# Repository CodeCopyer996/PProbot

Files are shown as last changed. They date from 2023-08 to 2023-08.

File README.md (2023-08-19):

# PProbot
My personal robot project, including 3D-models, trajectory tracking algorithm and control code, etc.
2.ctrl_system: IDE:STM32CUBEIDE MCU:STM32F427IIH6
3.Model: Solidworks 3D models
4.Docs: Article & Logs
5.QT: some QT practices, useless
6.CAD: .dwg files
7.Matlab:SimMechanics visual simulation; Simulink Trajectory tracking control simulation; Robotics-toolbox kinematics simulation;
demo video: 【PProbot四关节转动演示】 https://www.bilibili.com/video/BV1uu4y117B4/?share_source=copy_web&vd_source=224ee29a92f0b972809e3df01ed2ee81
3Dmodel
matlab_robotic
realrobot

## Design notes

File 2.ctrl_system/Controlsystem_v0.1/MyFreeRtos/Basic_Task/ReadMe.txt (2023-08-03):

注意！！！此文件为基础文件，主要用于辅助完成其他任务，
具体包括：
1.LED函数定义
2.Key函数定义
3.Usart与printf函数重定义
4.DMA函数定义

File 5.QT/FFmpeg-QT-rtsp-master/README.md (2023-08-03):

#                                  2018年7月8日更---程序使用说明
（1）首先将代码下载到本地，并解压；
（2）下载附件中的FFmpeg压缩包，解压后文件夹以FFmpeg命名，并和源码放入同一文件夹下；
（3）利用Qt creator Debug/release后，将FFmpeg文件夹下“dll”文件夹中的所有文件复制到含有.exe文件的文件夹（名称为Debug或release）下；
（4）再次点击Debug或release即可正常运行。

# FFmpeg-QT实现摄像头rtsp实时显示
1. 程序运行平台：（1）win10 64bit         （2）Qt Creator 4.3.1
2. 程序需要的库：（1）Qt 5.9.1(MSVC 2015,32bit) （2）FFmpeg 2.5.2
3. 程序流程图：
	程序流程图如图1所示，图中所示的主函数部分主要完成界面的构建、播放线程的建立以及参考坐标系的建立。图1展示了整个程序的运行流程。

图1 程序流程图
 
4. 程序界面：
	程序运行界面如图2所示。

 图2 程序运行界面

5. 主要功能：
	该界面主要实现四个功能：
（1）.读取摄像头视频流（rtsp），并实时显示到主界面上（注：存在0.7s左右的延时，延时测试过程如图3所示）；

 图3 延时测试过程

（2）.将rtsp视频流经过FFmpeg解码后的YUV数据转化成RGB32数据，提取其中的R（红色）通道，并在界面中的小窗显示（如图2中的左上角部分）；
（3）.将水下机器人的横滚角反映在界面上（如图2中，中间部分的虚线“十字”为水平和竖直参考位置；实线“十字”为横滚运动后机器人相对参考位置的角度变化，图示为模拟横滚角为10度的情形）。
（4）.若程序掉电，再次上电后能够自动地建立连接。

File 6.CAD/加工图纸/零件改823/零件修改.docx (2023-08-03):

1. 大臂支架左：过盈孔大的太大了，箭头指的孔应该打27.9，结果打了28.5的孔，比轴承大了没法用，需重做；

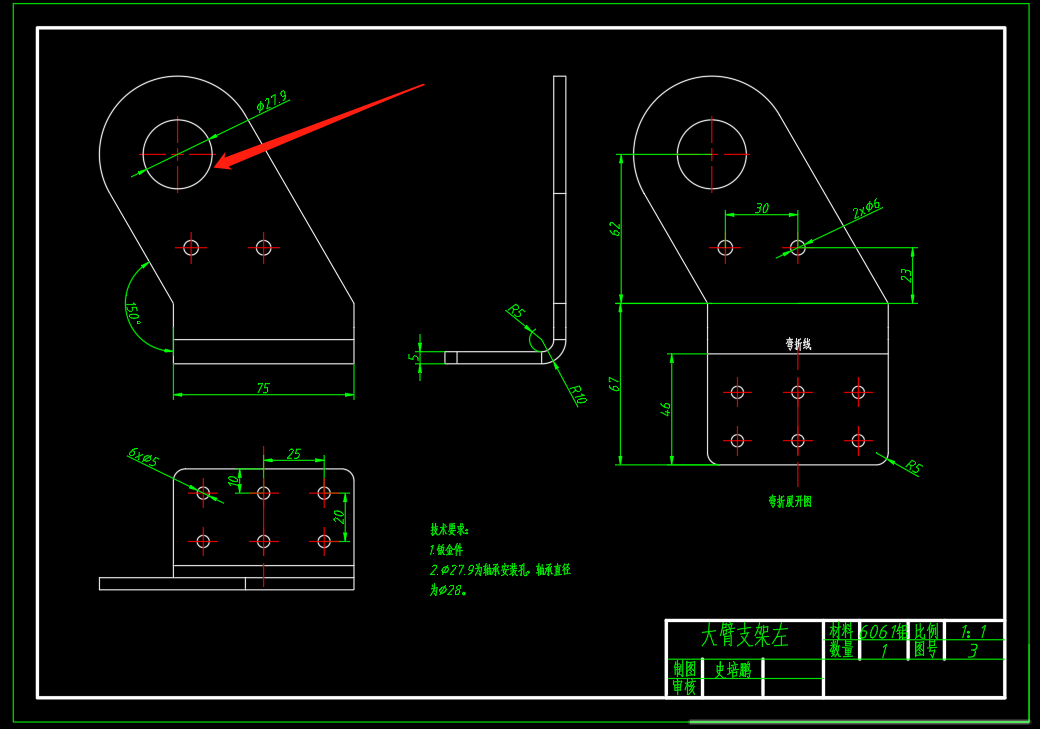
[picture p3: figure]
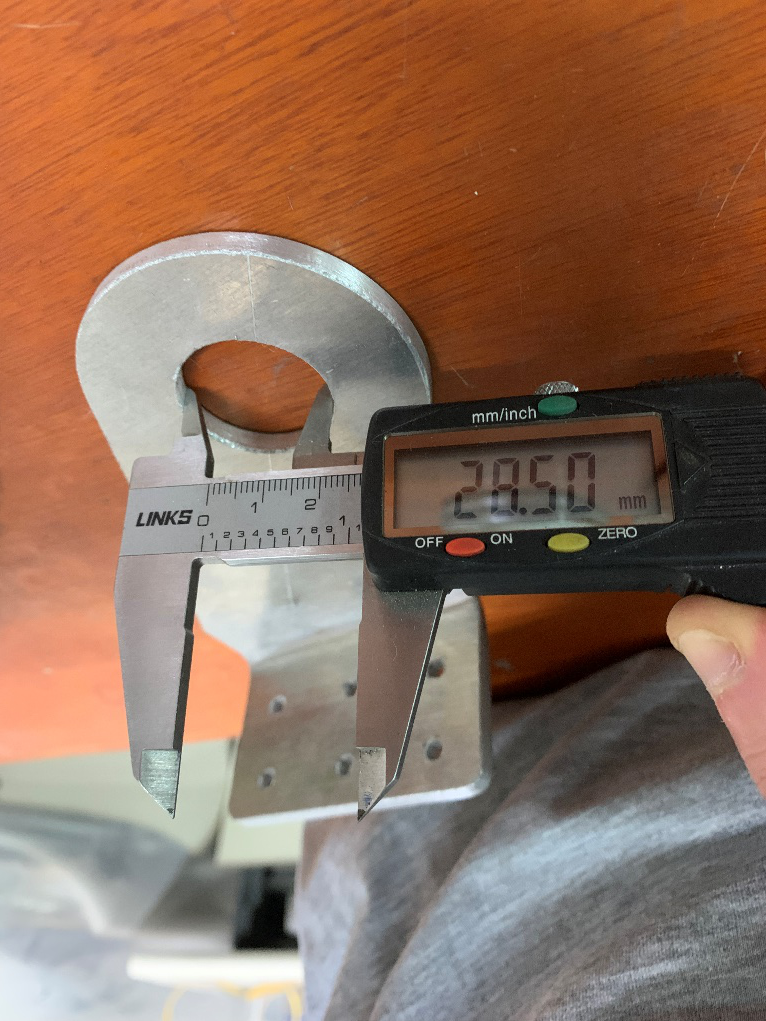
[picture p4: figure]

2. 小臂支架右，做的跟小臂支架左一样了，两个件孔是不一样的，需要重做；

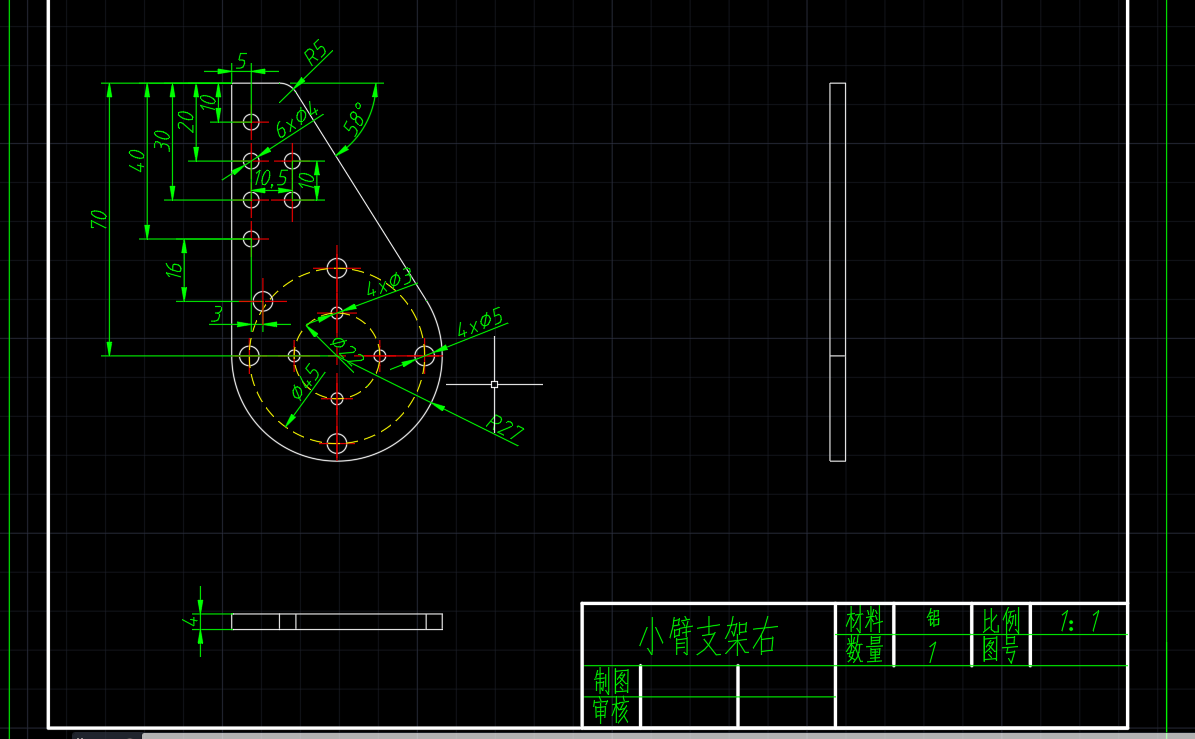
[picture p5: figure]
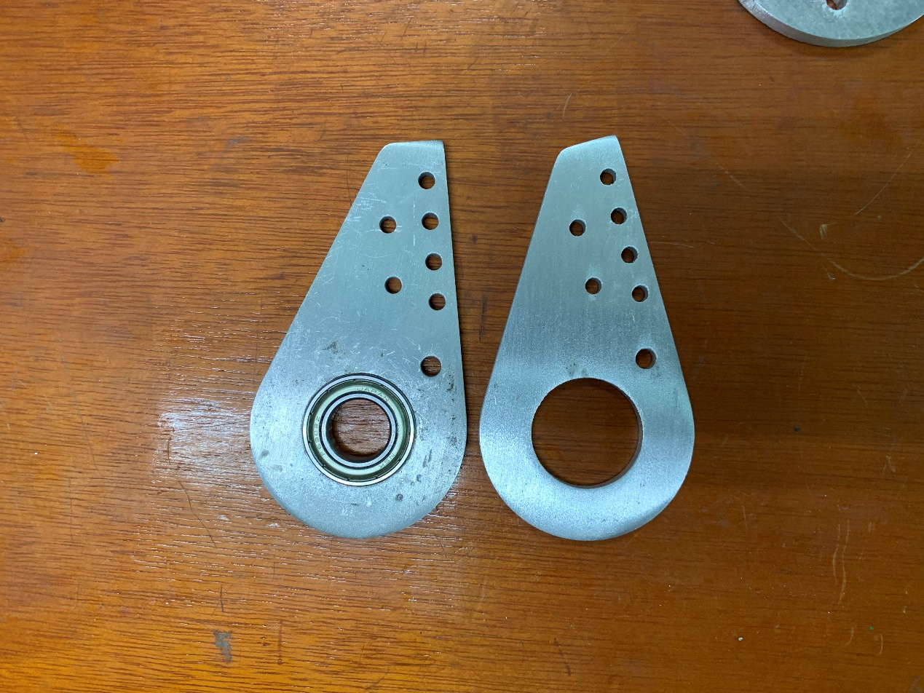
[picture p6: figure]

3. 大臂右，图纸少画了一组孔，可以修改；

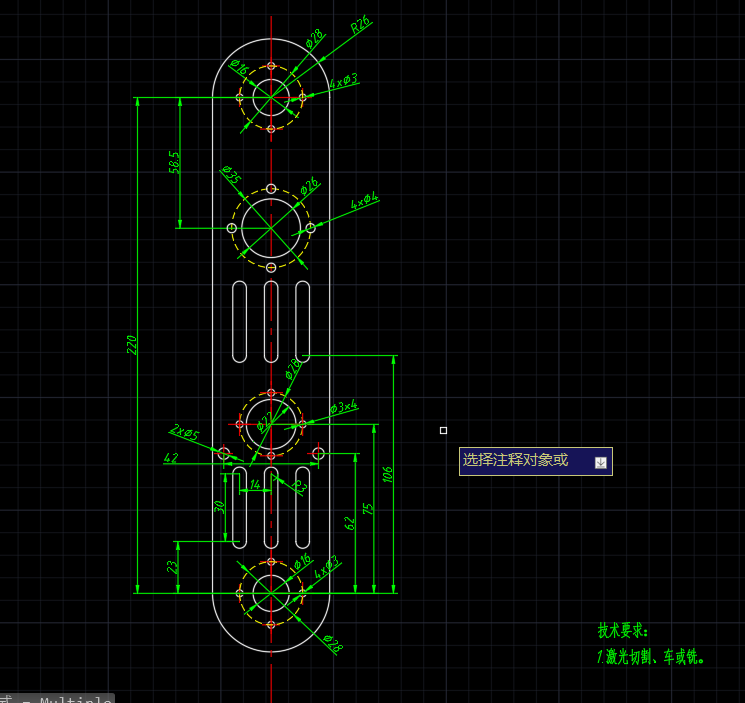
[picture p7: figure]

4. 大臂支架右：弯折方向反了，可以重新弯折；

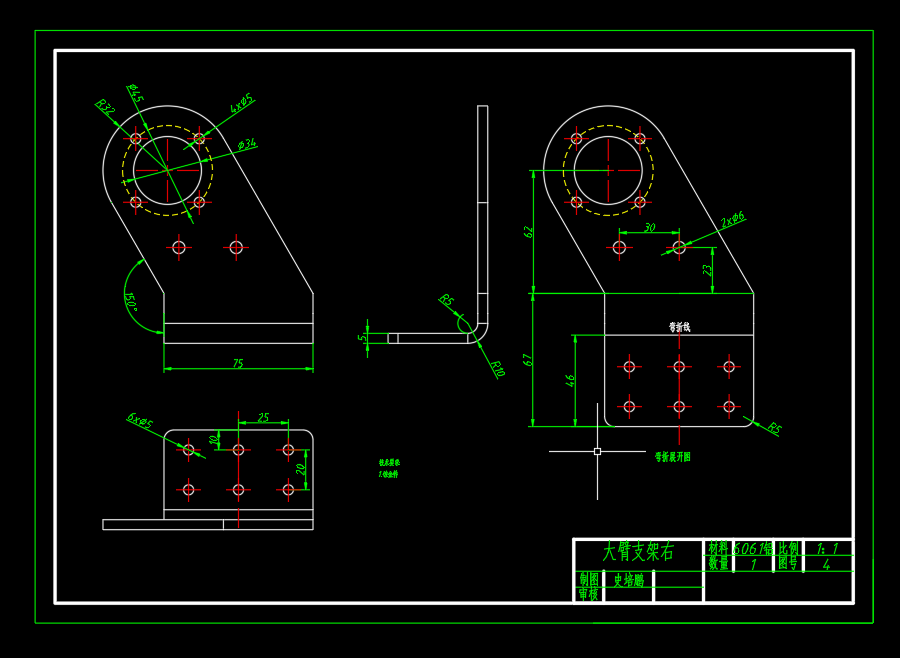
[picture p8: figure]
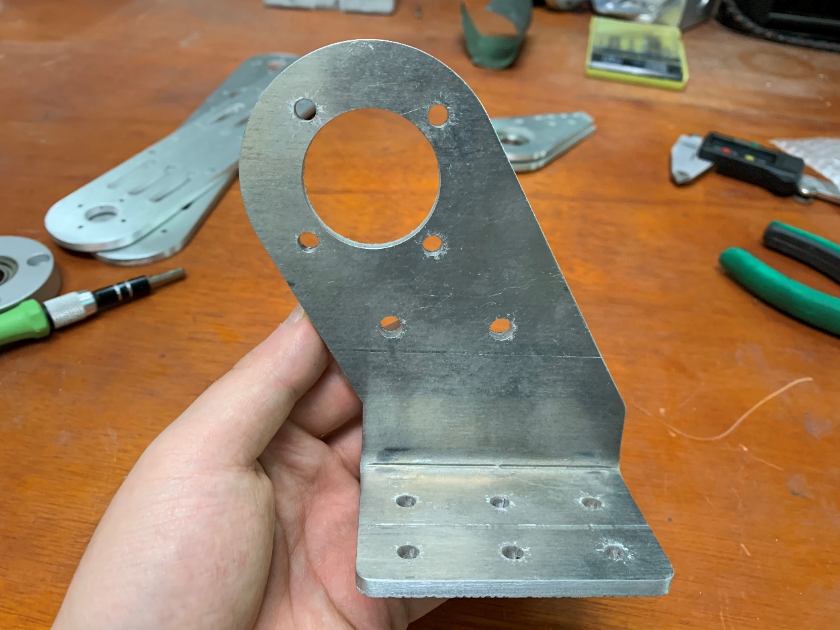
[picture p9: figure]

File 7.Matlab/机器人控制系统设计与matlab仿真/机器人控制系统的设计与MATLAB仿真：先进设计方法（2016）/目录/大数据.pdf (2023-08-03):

01 | Spark大数据分析与实战（大数据技术与应用丛书）
ISBN：9787302534327 | 作者：黑马程序员
定价：49.0元 | 出版日期：2019-09-01

传智播客编写，实用性强，案例翔实，配套数字资源丰富。

■PPT | □源码 | ■大纲 | □视频 | □教案 | □答案

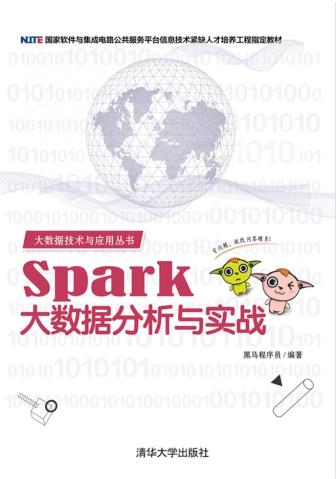
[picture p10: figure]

02 | 大数据安全与隐私保护（信息安全理论与技术系列丛书）
ISBN：9787302510451 | 作者：冯登国 等
定价：45.0元 | 出版日期：2018-02-01

“十三五”国家重点图书，全面阐述大数据安全与隐私保护领域理 论基础与最新进展。

■PPT | □源码 | □大纲 | □视频 | □教案 | □答案
03 | 大数据技术与应用（大数据技术与应用专业规划教材）
ISBN：9787302451815 | 作者：娄岩
定价：32.0元 | 出版日期：2016-01-01

本书是将大数据这一计算机前沿科学和基础教学有机结合的典范教 材，由浅入深地剖析了大数据的分析处理方法和技术手段。

■PPT | □源码 | □大纲 | □视频 | □教案 | □答案

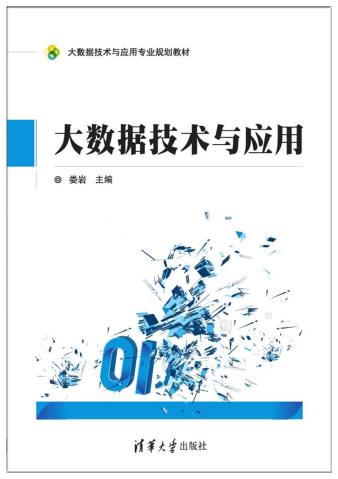
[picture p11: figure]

04 | 大数据可视化技术（大数据系列丛书）
ISBN：9787302449782 | 作者：周苏、张丽娜、王文
定价：44.5元 | 出版日期：2016-01-01

大数据可视化技术更注重技术的理解、掌握和应用，系统全面地介 绍可视化技术的基础知识和基本技能！

■PPT | □源码 | □大纲 | □视频 | □教案 | □答案

大数据挖掘及应用（大数据系列丛书） | 05
ISBN：9787302469278 | 作者：王国胤、刘群、于洪、曾宪华
定价：59.5元 | 出版日期：2017-07-01

本书是大数据系列丛书之一，涵盖大数据挖掘及应用领域的理论知 识、方法、技术、案例等重要内容，并配套视频课程及电子资源 ，是深入学习大数据挖掘理论和实践的专业教材。

■PPT | ■源码 | □大纲 | □视频 | □教案 | ■答案

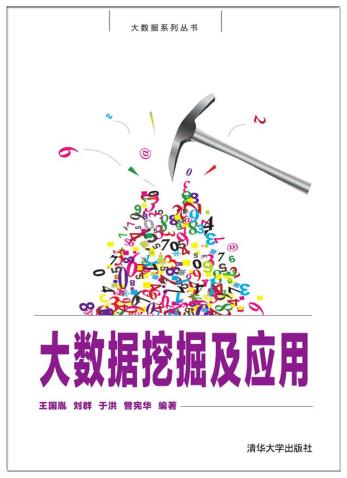
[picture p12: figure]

大数据挖掘与应用（大数据技术与应用专业规划教材） | 06
ISBN：9787302460435 | 作者：王振武
定价：49.5元 | 出版日期：2017-06-01

理论和实践相结合，充分融入产业界的先进理念，基于阿里云数加 平台进行演示，形象生动地使读者理解和掌握抽象的数据挖掘算法

■PPT | ■源码 | □大纲 | □视频 | □教案 | □答案
大数据智能分析 | 07

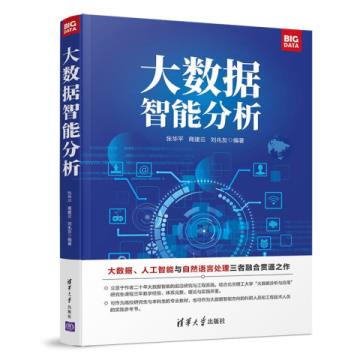
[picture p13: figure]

ISBN：9787302531173 | 作者：张华平、商建云、刘兆友
定价：59.8元 | 出版日期：2019-01-01

大数据智能，从数据量变到智能质变，提供课件及其他相关资源。

■PPT | □源码 | □大纲 | □视频 | □教案 | □答案
数据仓库与数据挖掘（第二版）（21世纪高等学校计算机专业核心课程规划... | 08
ISBN：9787302483991 | 作者：陈志泊、韩慧、王建新、孙俏、聂耿青
定价：39.0元 | 出版日期：2017-01-01

本书主要介绍数据仓库和数据挖掘技术的基本原理和应用方法

■PPT | □源码 | □大纲 | □视频 | □教案 | □答案

09 | 数据仓库与数据挖掘应用教程（21世纪高等学校电子商务专业规划教材）
ISBN：9787302430773 | 作者：李春葆、蒋林、陈良臣、喻丹丹、曾平
定价：39.5元 | 出版日期：2016-01-01

本书从介绍数据仓库和数据挖掘的基本概念出发，由简单到复杂 ，循序渐进介绍数据仓库和数据挖掘系统的开发过程，适合作为高 等学校大数据、电子商务专业教材

■PPT | □源码 | □大纲 | □视频 | □教案 | □答案

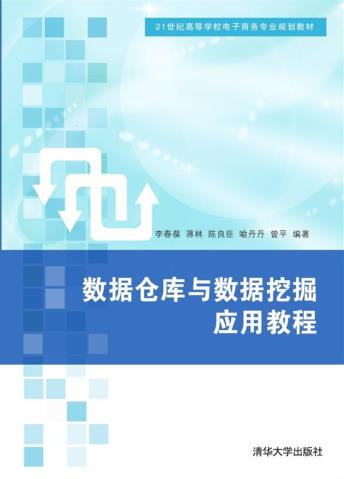
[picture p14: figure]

10 | 数据分析与数据挖掘（计算机科学与技术学科前沿丛书 计算机科学与技术...
ISBN：9787302493662 | 作者：喻梅 于健 主编；王建荣 王庆节 ...
定价：39.5元 | 出版日期：2018-04-01

“十三五”国家重点图书。紧密追踪当前科技前沿、数据科学热点 。算法由浅入深、由原理到应用，有利于学习和理解

■PPT | □源码 | □大纲 | □视频 | □教案 | □答案

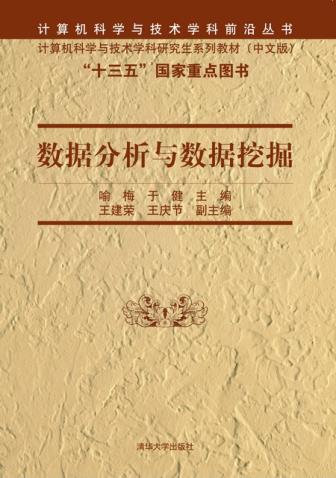
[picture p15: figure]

11 | 数据科学
ISBN：9787302436997 | 作者：朝乐门
定价：49.0元 | 出版日期：2016-08-01

本书是系统阐述数据科学的重要专著，深入浅出地讲解了大数据及 其背后的新理论、新方法与新技术，是大数据时代必读的经典书籍 之一。

■PPT | □源码 | □大纲 | □视频 | □教案 | □答案
12 | 数据科学理论与实践（第2版）（全国高校大数据教育联盟系列教材）

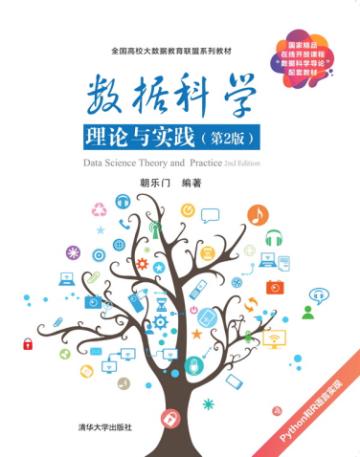
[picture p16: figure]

ISBN：9787302531913 | 作者：朝乐门
定价：69.8元 | 出版日期：2019-09-01

（1）国家精品开放在线课程《数据科学导论》的配套教材（2）一 本系统讲解全球范围内的数据科学的新理论与代表性实践的教材

■PPT | □源码 | □大纲 | □视频 | □教案 | □答案

数据科学理论与实践（全国高校大数据教育联盟系列教材） | 13
ISBN：9787302480549 | 作者：朝乐门
定价：59.0元 | 出版日期：2017-01-01

本书系统讲解数据科学的核心理论与典型实践，是一本“既有理论 高度，又有实践深度”的开创性教材。

■PPT | □源码 | □大纲 | □视频 | □教案 | □答案
数据可视化原理及应用（大数据技术与应用专业规划教材） | 14
ISBN：9787302531777 | 作者：樊银亭 夏敏捷 编著
定价：59.9元 | 出版日期：2019-01-01

本书理论与实际相结合，重点介绍最新的数据化技术D3，配套资源 丰富

■PPT | ■源码 | ■大纲 | □视频 | □教案 | □答案

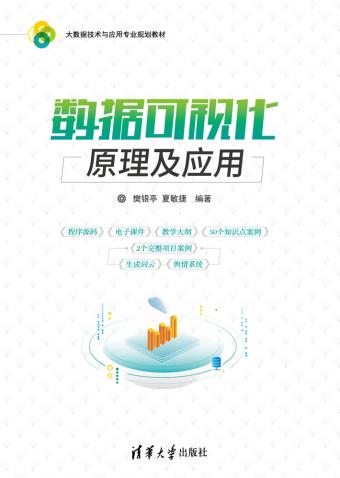
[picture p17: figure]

数据挖掘实用案例分析（大数据技术与应用专业规划教材） | 15
ISBN：9787302490494 | 作者：赵卫东 董亮
定价：49.0元 | 出版日期：2018-02-01

本书结合项目实践，对数据挖掘的核心问题进行了总结，并以案例 说明数据挖掘过程每个步骤需要关注之处；立足实际应用，突出实 际数据分析项目中的思路，以及数据分析中的难点。

■PPT | □源码 | □大纲 | □视频 | □教案 | □答案
数据挖掘算法原理与实现(第2版)（计算机系列教材） | 16

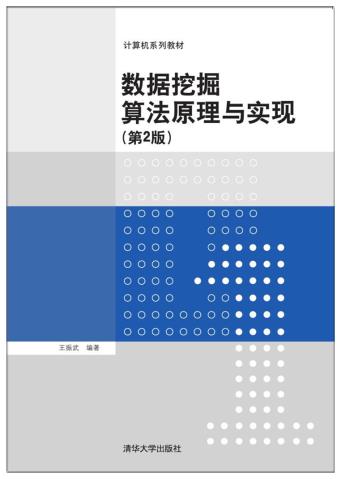
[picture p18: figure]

ISBN：9787302454151 | 作者：王振武
定价：35.0元 | 出版日期：2017-01-01

理论与实践结合非常实用的数据挖掘教材。

■PPT | □源码 | □大纲 | □视频 | □教案 | □答案

17 | 数据挖掘原理与算法（第3版）（21世纪高等学校计算机专业核心课程规划...
ISBN：9787302415817 | 作者：毛国君 段立娟
定价：49.0元 | 出版日期：2016-01-01

普通高等教育“十一五”国家级规划教材。

■PPT | □源码 | □大纲 | □视频 | □教案 | □答案
18 | 云计算导论（大数据技术与应用专业规划教材）
ISBN：9787302458050 | 作者：吕云翔、张璐、王佳玮
定价：29.0元 | 出版日期：2017-02-01

本书定位为“云计算导论”课程的专业教材，旨在传授读者云计算 的基础入门知识，本书也适合非计算机专业学生以及广大计算机爱 好者阅读

■PPT | □源码 | ■大纲 | □视频 | □教案 | □答案

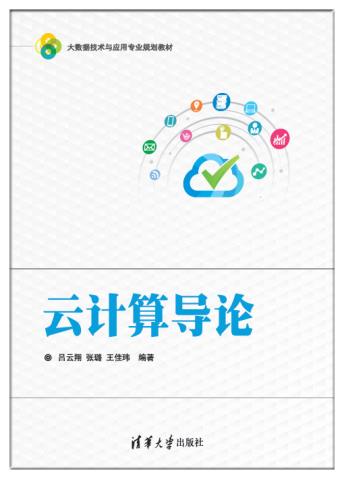
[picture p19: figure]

19 | 云计算与大数据技术理论及应用（大数据技术与应用专业规划教材）
ISBN：9787302524458 | 作者：林伟伟、彭绍亮
定价：89.0元 | 出版日期：2019-07-01

本书内容新颖先进，知识系统全面，技术深入易学

■PPT | □源码 | □大纲 | □视频 | □教案 | □答案

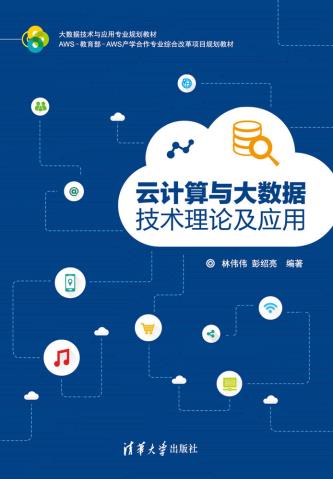
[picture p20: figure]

20 | Hadoop大数据技术原理与应用（大数据技术与应用丛书）
ISBN：9787302524403 | 作者：黑马程序员
定价：39.0元 | 出版日期：2019-05-01

传智博客倾情奉献，全面系统地讲解了Hadoop完整的技术体系，范 例翔实，配套教学资源丰富。

■PPT | □源码 | □大纲 | □视频 | □教案 | □答案

商务智能与数据挖掘（第2版）（大数据技术与应用专业规划教材） | 21
ISBN：9787302486312 | 作者：蔡晓妍、杨黎斌、张晓婷、李梅
定价：39.5元 | 出版日期：2018-03-01

阐述商务智能的两种关键技术——数据仓库和联机分析，最后介绍 数据挖掘在商务智能中的应用

■PPT | □源码 | □大纲 | □视频 | □教案 | □答案

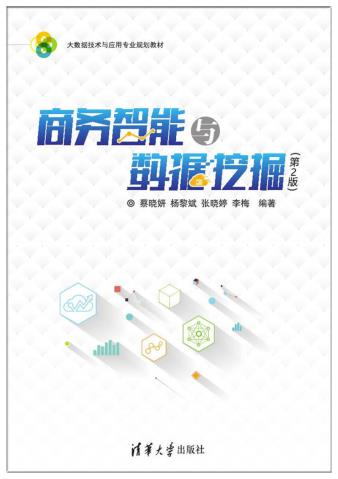
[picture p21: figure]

统计学——方法、数据与R的应用（大数据与人工智能技术丛书） | 22
ISBN：9787302529606 | 作者：刘超
定价：39.8元 | 出版日期：2019-09-01

以大量数据为基础，使用非常方便的R软件为读者呈现可见即可得 的统计分析过程。

■PPT | ■源码 | ■大纲 | □视频 | □教案 | □答案
虚拟化与云计算系统运维管理-微课版（21世纪高等学校计算机类课程创新... | 23
ISBN：9787302480532 | 作者：杨海艳、冯理明、张凌 主编，杜...
定价：49.5元 | 出版日期：2017-09-01

35段共500分钟微课视频，扫二维码直接观看，7大项目实战，详解 虚拟化与云计算基础系统运维管理。

■PPT | □源码 | ■大纲 | ■视频 | □教案 | □答案

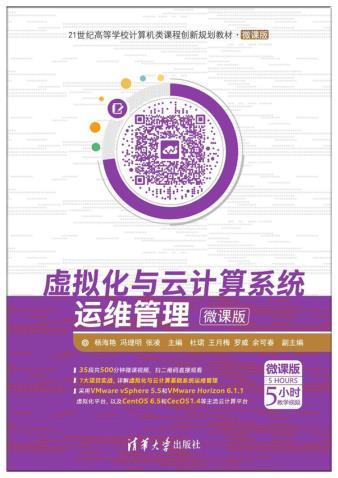
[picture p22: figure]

大数据技术与应用-微课视频版 | 24
ISBN：9787302538431 | 作者：肖政宏
定价：49.8元 | 出版日期：2020-06-01

本书可以作为高等院校大数据技术相关课程本科生教材，也可以作 为大数据技术基础相关课程研究生教材，还可以作为从事大数据相 关工作的工程技术人员的参考用书。

■PPT | ■源码 | ■大纲 | ■视频 | □教案 | ■答案

25 | 大数据可视化技术与应用-微课视频版
ISBN：9787302547501 | 作者：黄源
定价：49.8元 | 出版日期：2020-06-01

将理论与实践操作相结合，通过大量的案例帮助读者快速了解和应 用大数据分析的相关技术,并且对于书中重要的、核心的知识点加大 练习的比例，以使读者达到熟练应用的目的。

■PPT | ■源码 | ■大纲 | ■视频 | □教案 | □答案

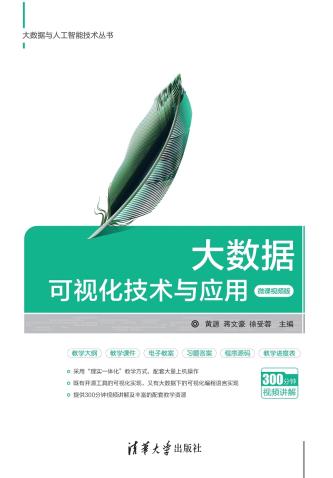
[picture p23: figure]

26 | 数据库技术及应用——基于SQL Server 2016和MongoDB
ISBN：9787302536185 | 作者：马忠贵
定价：69.8元 | 出版日期：2020-06-01

采用关系数据库（SQL Server 2016）和非关系数据库 （MongoDB）对照阐述，介绍各自的优势。

■PPT | ■源码 | ■大纲 | ■视频 | □教案 | □答案

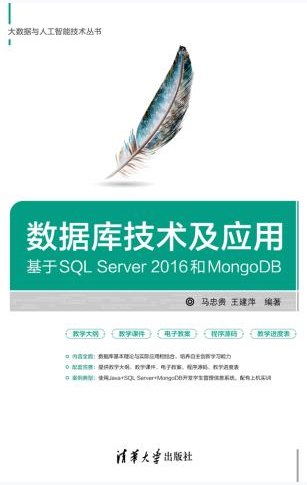
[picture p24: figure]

27 | Python数据分析与可视化-微课视频版
ISBN：9787302546665 | 作者：魏伟一
定价：49.0元 | 出版日期：2020-06-01
■PPT | ■源码 | ■大纲 | □视频 | □教案 | □答案
28 | Python爬虫大数据采集与挖掘-微课视频版

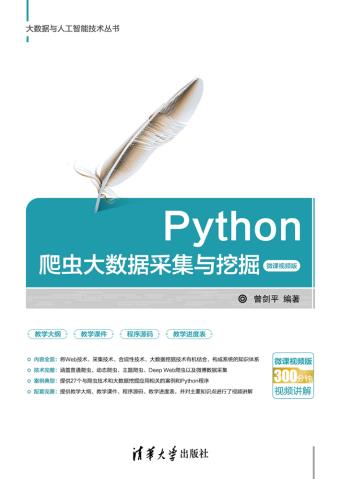
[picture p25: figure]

ISBN：9787302540540 | 作者：曾剑平
定价：59.8元 | 出版日期：2020-06-01

300分钟视频讲解

■PPT | ■源码 | ■大纲 | ■视频 | □教案 | ■答案

大数据分析：Python爬虫、数据清洗和数据可视化 | 29
ISBN：9787302530541 | 作者：黄源
定价：59.8元 | 出版日期：2020-06-01
大数据导论 | 30
ISBN：9787302541905 | 作者：张凯
定价：49.8元 | 出版日期：2020-06-01

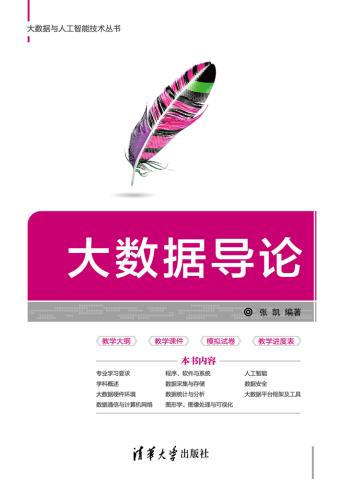
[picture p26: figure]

统计学——方法、数据与R的应用 | 31
ISBN：9787302529606 | 作者：刘超
定价：39.8元 | 出版日期：2019-09-01
大数据专业英语教程（大数据与人工智能技术丛书） | 32


ISBN：9787302526926 | 作者：张强华、刘俊辉、郑聪玲、司爱侠
定价：39.8元 | 出版日期：2019-07-01

以Unit为单位，每一Unit由以下几部分组成： 课文； 单词、词组 及缩略语； 难句讲解； 习题； 科技英语翻译知识； 阅读材料.

■PPT | □源码 | ■大纲 | □视频 | □教案 | □答案

33 | 云计算与大数据技术（大数据与人工智能技术丛书）
ISBN：9787302501466 | 作者：吕云翔、钟巧灵、张璐、王佳玮
定价：35.0元 | 出版日期：2018-01-01

注重云计算与大数据基本概念的讲解，以案例的方式梳理知识脉络 和要点，提供综合云计算实验案例

■PPT | □源码 | ■大纲 | □视频 | □教案 | □答案
34 | Python数据分析与实践
ISBN：9787302515791 | 作者：柳毅
定价：59.0元 | 出版日期：2019-06-01

浙江省“十三五”教材

■PPT | ■源码 | ■大纲 | ■视频 | □教案 | ■答案


35 | Python机器学习——数据分析与评分卡建模（微课版）
ISBN：9787302516842 | 作者：翟锟
定价：49.0元 | 出版日期：2019-05-01

本书从零基础入门，注重实战，内含10个学习实例，3个完整的项 目案例，详细讲解了Python的环境搭建、基本语法结构、趣味应用 、分析与建模以及完整的项目案例。

■PPT | ■源码 | □大纲 | ■视频 | □教案 | □答案


36 | Hadoop+Spark大数据技术（微课版）
ISBN：9787302514275 | 作者：刘彬斌
定价：69.0元 | 出版日期：2018-01-01

内容分为大数据系统基础、Hadoop技术、Spark技术和项目实战4部 分。其中，Linux是学习大数据技术的基础，先从Linux入手，打下 坚实的基础，之后才能更好地学习Hadoop和Spark。

■PPT | ■源码 | □大纲 | ■视频 | □教案 | □答案

Python网络编程(Linux) | 37
ISBN：9787302504832 | 作者：赵宏
定价：39.0元 | 出版日期：2018-01-01

本书选用各项性能指标优良的Ubuntu作为Linux系统实例，以 Python为编程语言，理论结合实践，系统地讲解网络各层次的功能 、所包含的常用协议、数据报文格式，并给出实际操作的程序实例 。

■PPT | ■源码 | □大纲 | □视频 | □教案 | ■答案


机器学习入门到实战——MATLAB 实践应用 | 38
ISBN：9787302495147 | 作者：冷雨泉
定价：59.0元 | 出版日期：2019-03-01
在线广告——互联网广告系统的架构及算法 | 39
ISBN：9787302526520 | 作者：张亚东
定价：69.8元 | 出版日期：2019-08-01

微博技术总监详解互联网广告系统的架构及算法，揭秘互联网商业 变现技术，众多互联网公司管理层与技术人员推荐阅读。

■PPT | □源码 | □大纲 | □视频 | □教案 | □答案


大话数据科学——大数据与机器学习实战（基于R语言） | 40
ISBN：9787302551300 | 作者：陈文贤
定价：128.0元 | 出版日期：2020-07-01

多图多思想，缜密学习思维导图，全套学习课件，全彩印刷、卓越 体验。学习数据科学，看陈文贤老师的就对了。

■PPT | □源码 | □大纲 | □视频 | □教案 | □答案

41 | 大数据技术（微课版）（面向新工科专业建设计算机系列教材）
ISBN：9787302553632 | 作者：曹洁、孙玉胜
定价：59.0元 | 出版日期：2020-08-01

学习大数据技术非常实用的教材。

■PPT | □源码 | □大纲 | □视频 | □教案 | □答案


42 | 云计算导论（第2版）（大数据与人工智能技术丛书）
ISBN：9787302536901 | 作者：吕云翔
定价：49.8元 | 出版日期：2020-06-01

本书从云计算最基本的概念开始，由浅入深地带领读者领会云计算 的精髓，以梳理知识脉络和要点的方式，带领读者登堂入室。

■PPT | ■源码 | ■大纲 | ■视频 | □教案 | ■答案
43 | 大数据技术基础（21世纪高等学校通识教育规划教材）


ISBN：9787302557531 | 作者：宋旭东
定价：59.0元 | 出版日期：2020-08-01

融会贯通大数据概念与大数据技术及应用，便于读者更好理解和掌 握大数据技术及应用。

■PPT | ■源码 | ■大纲 | □视频 | □教案 | □答案

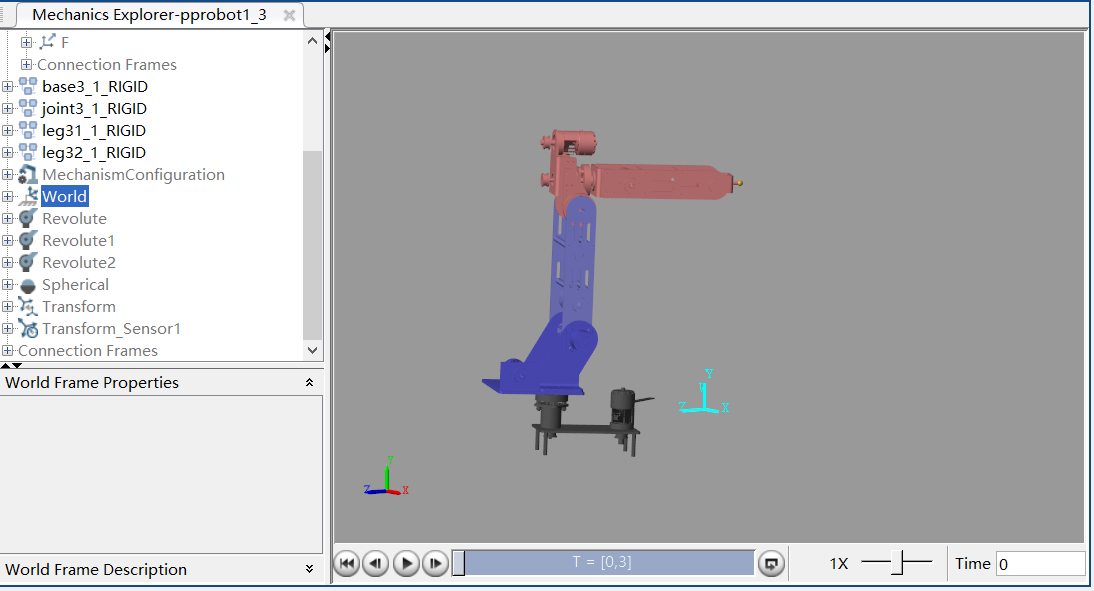
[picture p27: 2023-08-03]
7.Matlab/simulink_cut.png

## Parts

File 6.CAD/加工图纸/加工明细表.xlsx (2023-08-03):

名称 | 材料 | 板厚 | 数量 | 单价 | 总价 | 备注
大臂支架右 | 铝 | 5 | 1
大臂支架左 | 铝 | 5 | 1
小臂中 | 铝 | 4 | 1
小臂中支架 | 铝 | 4 | 1
爪 | 铝 | 4 | 1
大臂右 | 铝 | 5 | 1
大臂左 | 铝 | 5 | 1
小臂左 | 铝 | 5 | 1
小臂右 | 铝 | 5 | 1
小臂支架左 | 铝 | 4 | 1
小臂支架右 | 铝 | 4 | 1
轴承安装板 | 铝 | 4 | 1
底板F1 | 钢 | 5 | 1
底板F2 | 钢 | 5 | 1
61902法兰轴 | 铝 |  | 6
旋转轴 | 铝 |  | 3
 |  |  | 23 |  | 0

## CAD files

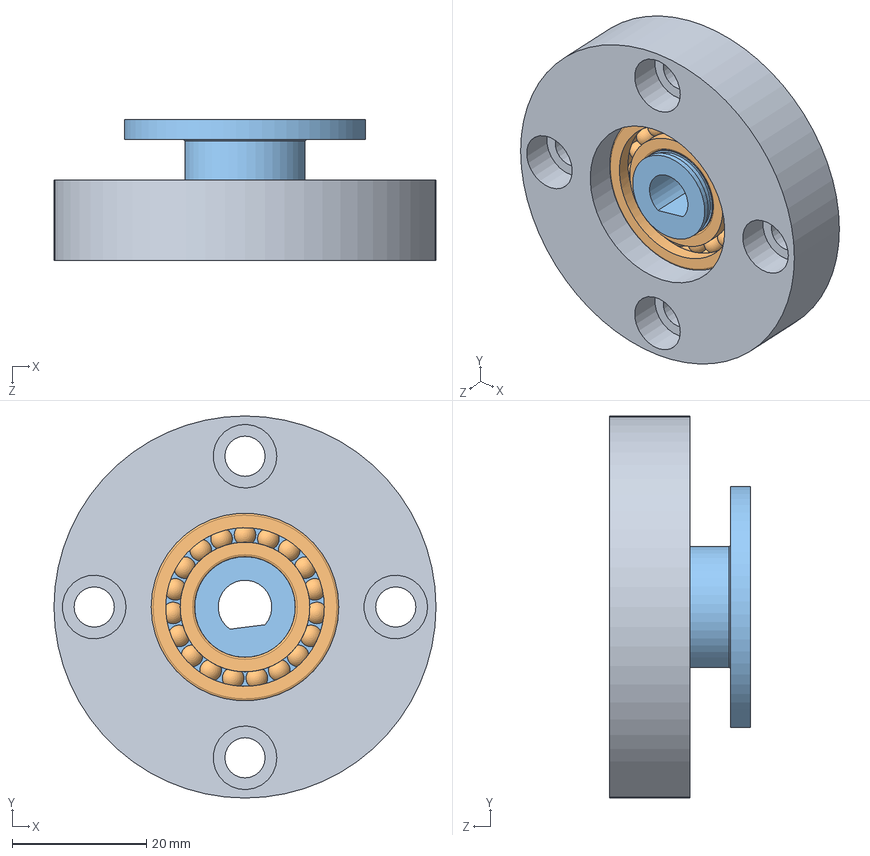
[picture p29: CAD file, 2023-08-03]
3.Model/轴承座.SLDASM
57.0 x 57.0 x 21.0 mm
轴承座
deep groove ball bearings gb
61902法兰

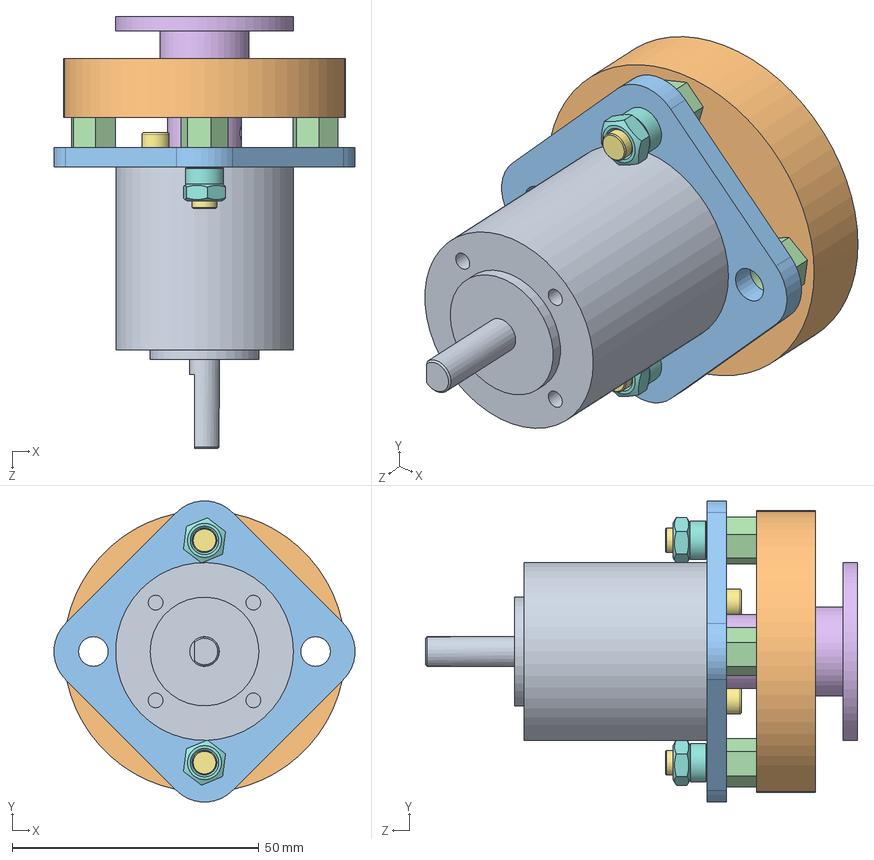
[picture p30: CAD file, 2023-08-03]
3.Model/减速器关节.SLDASM
60.9 x 60.9 x 87.5 mm
27：1双轴减速器
轴承座
减速器固定
铜柱M6x6 x 4
deep groove ball bearings gb
61902法兰
hexagon socket head cap screws gb x 4
prevailing torque type style 1 gb x 2

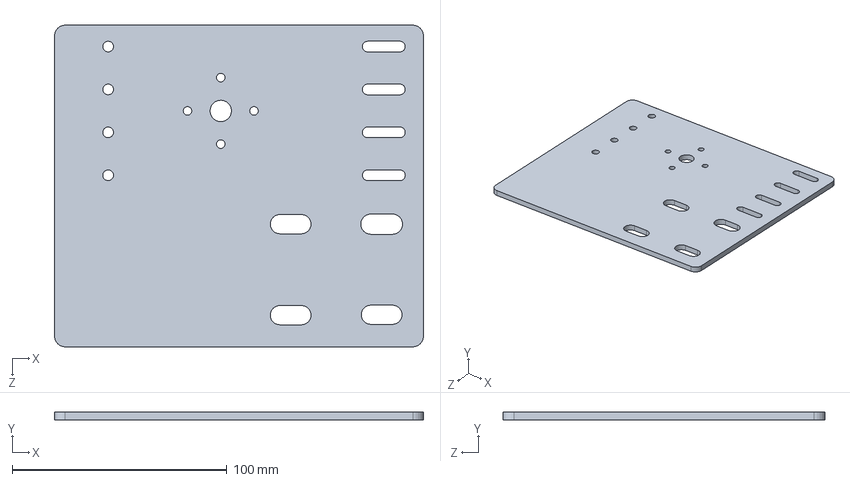
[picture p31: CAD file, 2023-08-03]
3.Model/对称支架.SLDPRT
172.0 x 3.68 x 150.0 mm

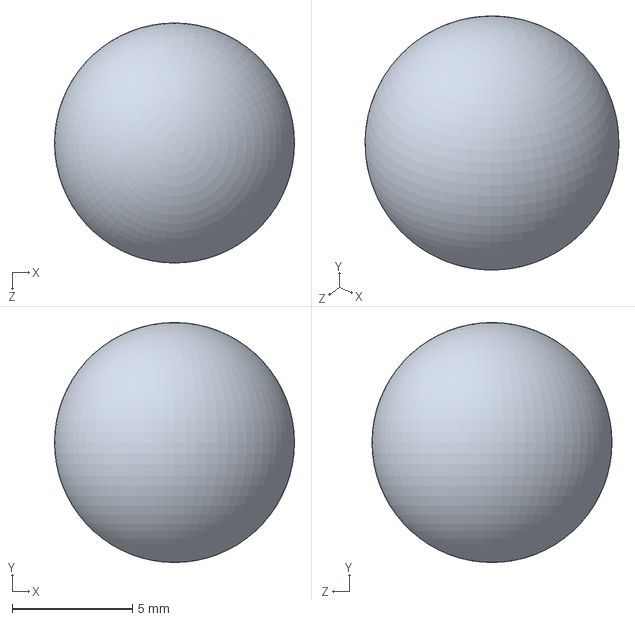
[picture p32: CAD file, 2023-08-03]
7.Matlab/ppRobot_matlab1.4/ball3.SLDPRT
10.0 x 10.0 x 10.0 mm

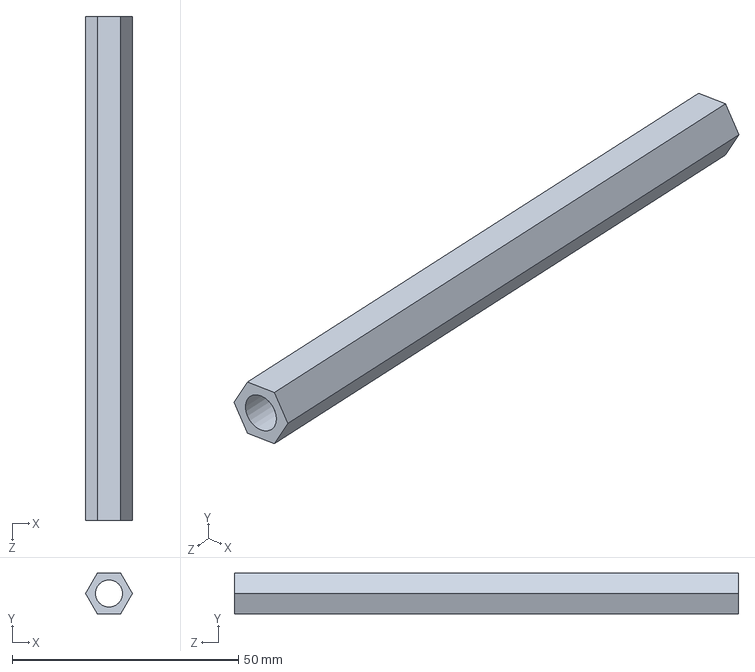
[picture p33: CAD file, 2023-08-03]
3.Model/111.5铜柱.SLDPRT
10.4 x 9.00 x 111.5 mm

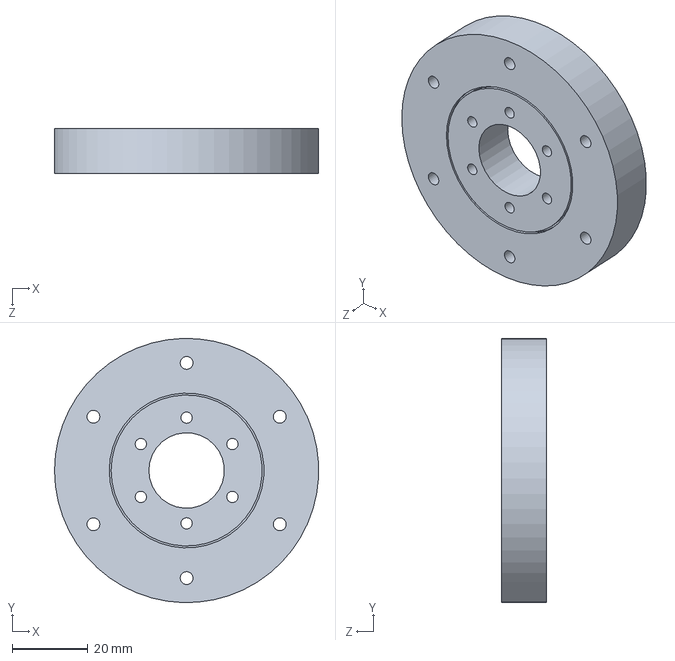
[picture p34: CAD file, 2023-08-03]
3.Model/交叉滚子轴承.SLDPRT
69.9 x 70.0 x 12.0 mm

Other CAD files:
6.CAD/加工图纸/底板F1.dwg
6.CAD/加工图纸/钢板类/底座F1_NO.1.dwg
6.CAD/加工图纸/铝板类/平板类（激光切割）/小臂左.dwg
6.CAD/加工图纸/铝板类/钣金板类/爪.dwg
6.CAD/加工图纸/零件改823/大臂支架左.dwg
6.CAD/加工图纸/云台法兰盘64.dwg
6.CAD/加工图纸/轴类/旋转轴.dwg
6.CAD/加工图纸/钢板类/底板F2_NO.2.dwg
6.CAD/加工图纸/铝板类/平板类（激光切割）/大臂左.dwg
6.CAD/加工图纸/铝板类/钣金板类/小臂中支架.dwg
6.CAD/加工图纸/零件改823/小臂支架右.dwg
7.Matlab/ppRobot_matlab1.4/ball3_默认_sldprt.STEP
3.Model/27：1双轴减速器.SLDPRT
3.Model/58铜柱.SLDPRT
3.Model/61902关节.SLDASM
3.Model/61902关节光孔.SLDASM
3.Model/61902法兰.SLDPRT
3.Model/61902法兰光孔.SLDPRT
3.Model/61902轴承座.SLDPRT
3.Model/61902轴承座薄.SLDPRT
3.Model/6902带挡边轴承.SLDPRT
3.Model/71铜柱.SLDPRT
3.Model/lianzhouqi.SLDPRT
3.Model/云台旋转板.SLDPRT
3.Model/云台法兰.SLDPRT
3.Model/云台法兰2.SLDPRT
3.Model/云台法兰42.SLDPRT
3.Model/云台联轴器8-10.SLDPRT
3.Model/减速器固定.SLDPRT
3.Model/同步轮6.SLDPRT
3.Model/同步轮8.SLDPRT
3.Model/地板.SLDPRT
3.Model/大臂.SLDPRT
3.Model/大臂左.SLDPRT
3.Model/大臂支架.SLDPRT
3.Model/大臂支架右.SLDPRT
3.Model/大臂支架左.SLDPRT
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

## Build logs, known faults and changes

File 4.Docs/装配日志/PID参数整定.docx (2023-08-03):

位置PID

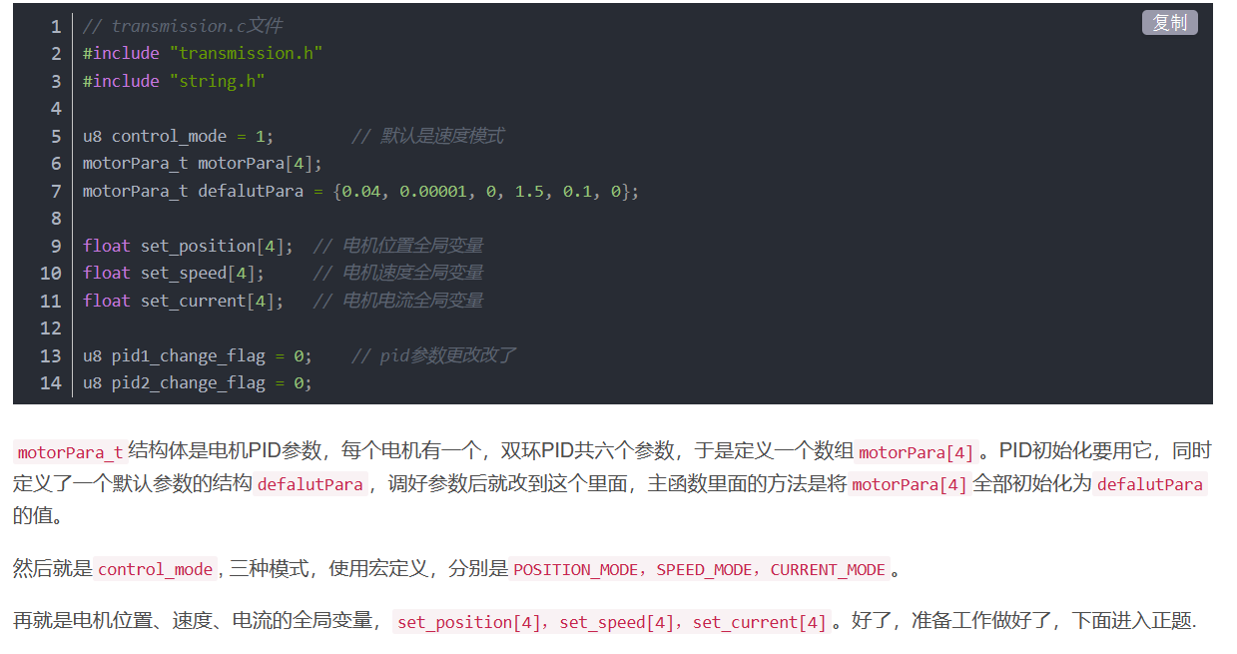
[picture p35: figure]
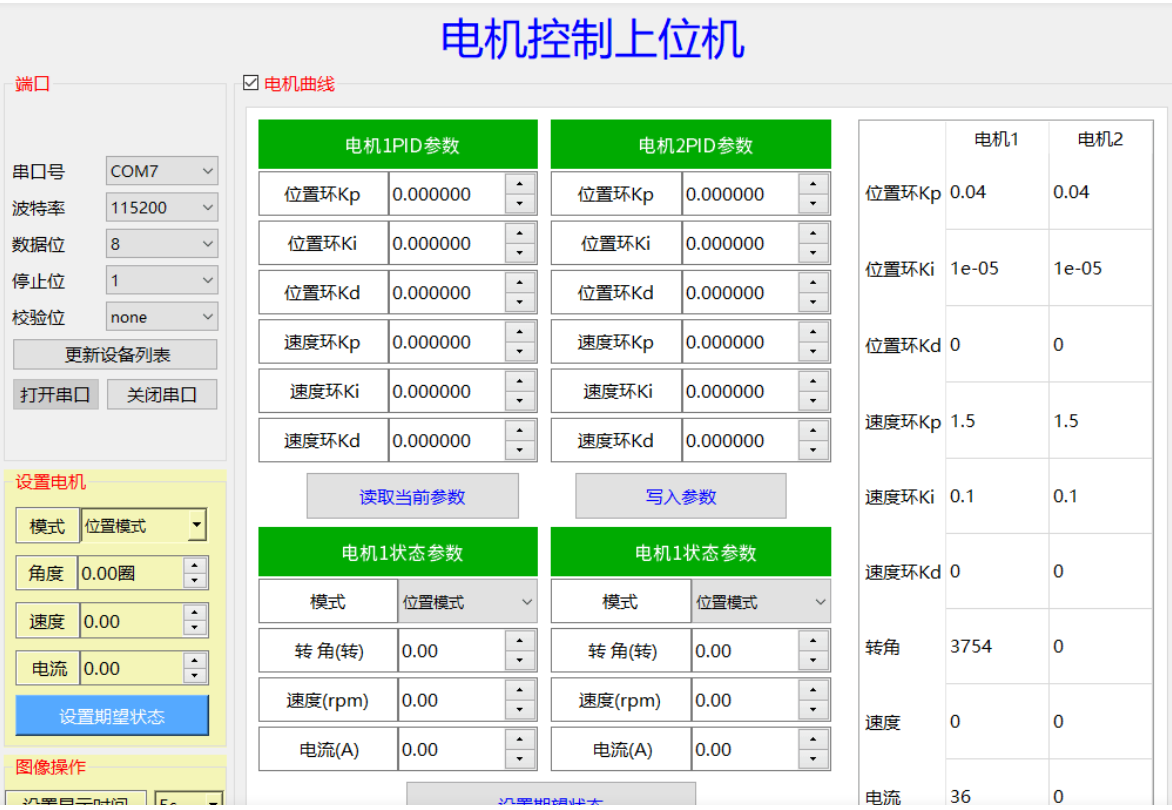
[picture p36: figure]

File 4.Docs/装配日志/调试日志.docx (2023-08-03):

6/16/2023 10:56 AM

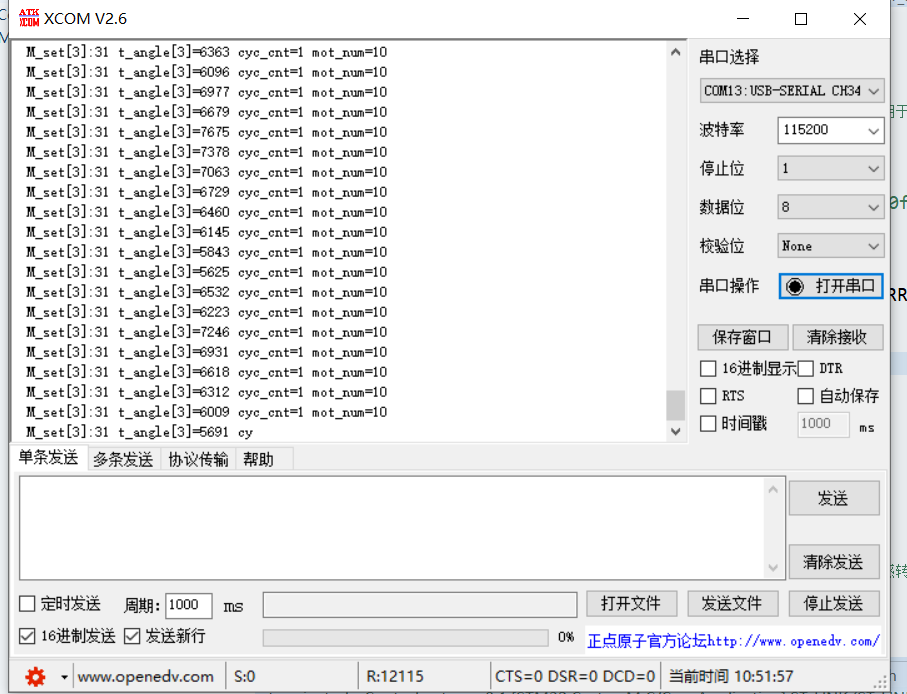
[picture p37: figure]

Issue:

转子转角更新出现问题，不符合设定的更新逻辑；（这个问题不应该出现

另外需要找到更好转子转数的判断条件，转子转速过快，大于feedback的时间间隔，就是在两个feedback时间间隔内，转子可能已经转了一圈或者更多，故在当前判断条件下会出现转了一圈甚至两圈但转数并不更新的情况，甚至在一段时间内转速恰好卡在这个bug区间，导致转子转数一直无法更新；

6/16/2023 11:34 AM

最终稳定：在一段较长时间内不再有波动，并且可以继续发送新的指令；

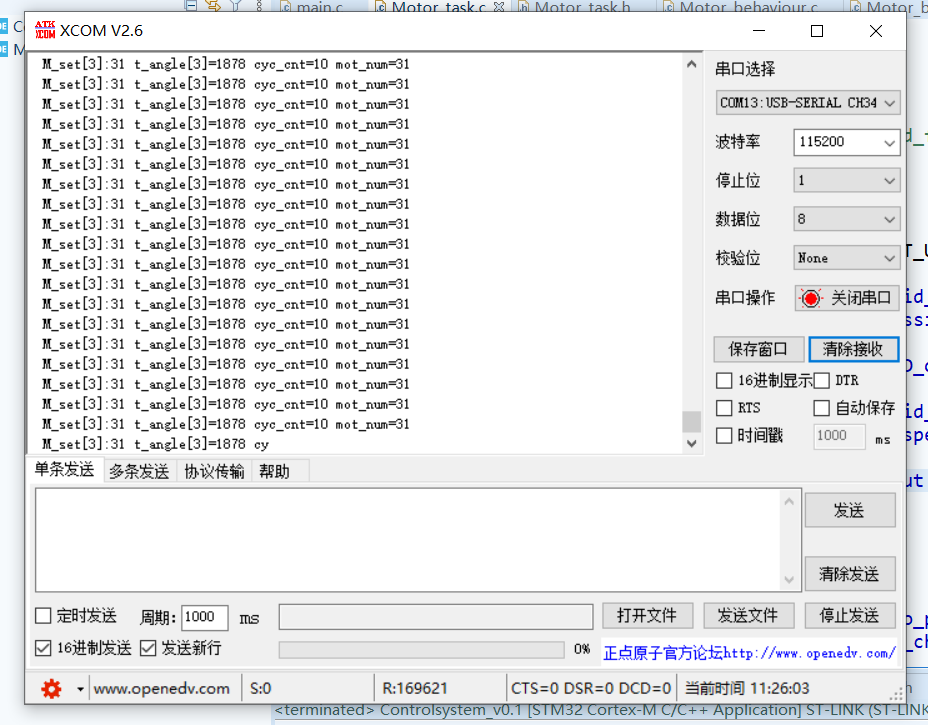
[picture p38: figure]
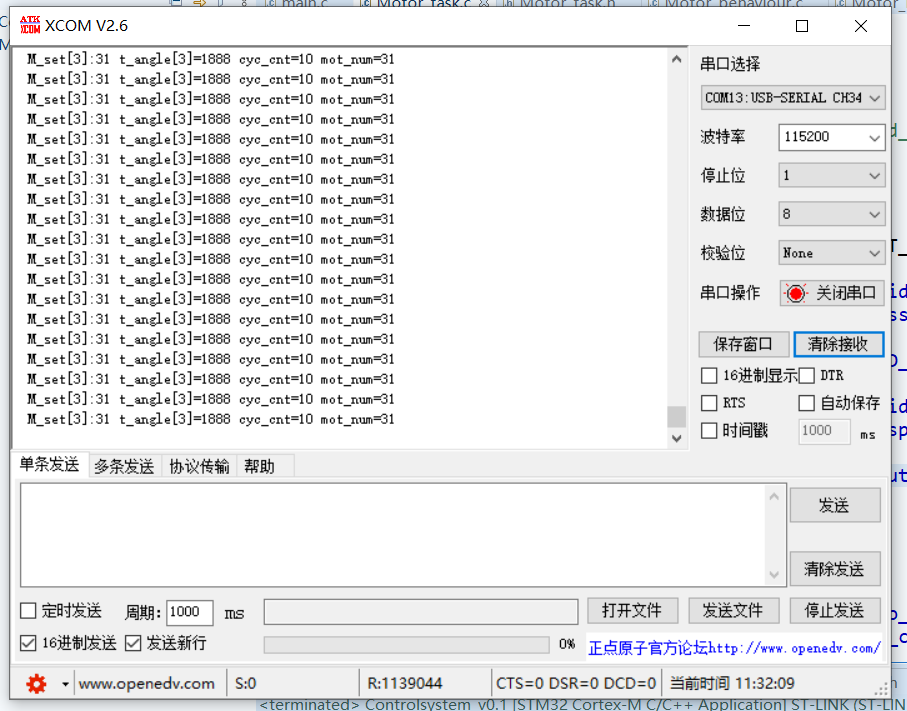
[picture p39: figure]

6/25/2023 4:28 PM

调试日志

Issue: cyc_cnt转数更新很魔性，不按规则来，查看后发现last_angle更新竟然比angle大

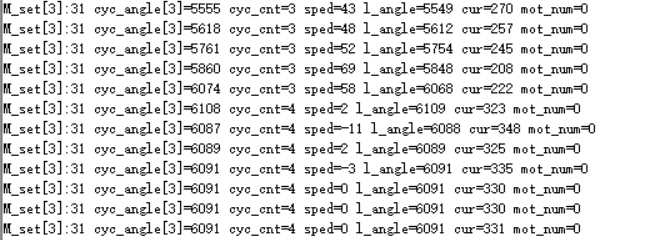
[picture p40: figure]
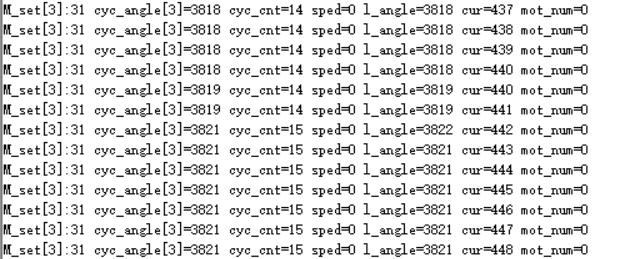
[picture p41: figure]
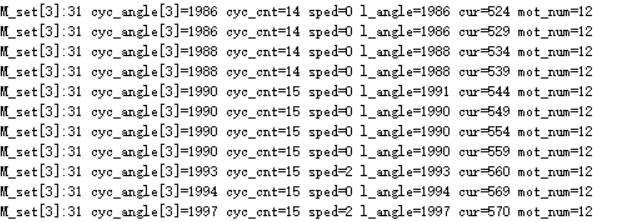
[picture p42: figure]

每次last_angle都比angle大1，就很离谱？？？而真正需要更新转数的情况一个都不更新，如下：

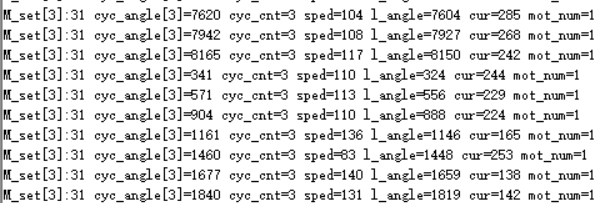
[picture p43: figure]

并且由此发现电机测量数据是自动更新的，不随feedback函数的频率更新，且更新速度更快，导致last_angle已经跟angle数值很接近了，无法再按照两数值的差值作为判断条件；

6/26/2023 8:33 PM

为解决电机内部编码器last_angle更新过快的问题，自行定义一个llast_angle，只在每次feedback函数时更新，这样当前angle和last_angle更新速率就保持一致了，解决了此问题，cyc_numcnt更新比较平稳，在此情况下电机输出轴的位置PID可以达到比较好的效果。

New issues:

1. 电机轴位置PID追踪目标值太慢了，解决：需要调参；
2. 当达到目标值附近时，电机速度变慢暂停，停止瞬间会出现speed反向的问题（应该是惯性导致），由于speed方向作为判定条件，会导致cyc_numcnt出现问题，比如正向转了一圈却因为暂停时出现负的速度导致圈数-1。解决：判定条件不再简单的speed<0或>0，令其>10 or <-10 ,简单滤波防抖；同理，cyc_numcnt转数更新的判定条件也采用的这种思路。

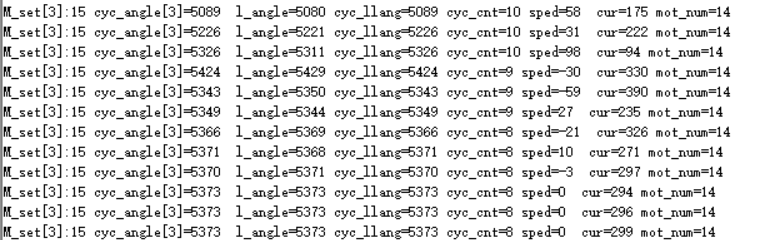
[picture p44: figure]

还是会出现这种极端情况，但是少了很多，调节了PID参数后旋转比较稳定。

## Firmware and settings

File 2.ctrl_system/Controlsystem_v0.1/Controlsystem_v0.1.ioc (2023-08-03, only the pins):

Mcu.UserName=STM32F427IIHx
PA13.Signal=SYS_JTMS-SWDIO
PA14.Signal=SYS_JTCK-SWCLK
PB0.Signal=ADCx_IN8
PB1.GPIO_Label=PRE_CLK1
PB1.Signal=GPIO_Output
PB2/BOOT1.GPIO_Label=USER_KEY
PB2/BOOT1.Signal=GPIO_Input
PB3.Signal=SYS_JTDO-SWO
PB6.Signal=USART1_TX
PB7.Signal=USART1_RX
PC14/OSC32_IN.Signal=RCC_OSC32_IN
PC15/OSC32_OUT.Signal=RCC_OSC32_OUT
PC3.GPIO_Label=PRE_DAT1
PC3.Signal=GPIO_Input
PD0.Signal=CAN1_RX
PD1.Signal=CAN1_TX
PD5.Signal=USART2_TX
PD6.Signal=USART2_RX
PD8.Signal=USART3_TX
PD9.Signal=USART3_RX
PE0.Signal=UART8_RX
PE1.Signal=UART8_TX
PE11.GPIO_Label=LED1
PE11.Signal=GPIO_Output
PE12.Signal=SPI4_SCK
PE4.GPIO_Label=NRF24L01_SPI_NSS
PE4.Signal=GPIO_Output
PE5.Signal=SPI4_MISO
PE6.Signal=SPI4_MOSI
PE7.Signal=UART7_RX
PE8.Signal=UART7_TX
PF10.GPIO_Label=NRF24L01_IRQ
PF10.Signal=GPIO_Input
PF14.GPIO_Label=LED0
PF14.Signal=GPIO_Output
PF6.GPIO_Label=SPI5_NSS
PF6.Signal=GPIO_Output
PF7.Signal=SPI5_SCK
PF8.Signal=SPI5_MISO
PF9.Signal=SPI5_MOSI
PG1.GPIO_Label=NRF_LED
PG1.Signal=GPIO_Output
PG13.GPIO_Label=NRF24L01_POWER
PG13.Signal=GPIO_Output
PG2.GPIO_Label=MPU6500_LED
PG2.Signal=GPIO_Output
PG3.GPIO_Label=IST_LED
PG3.Signal=GPIO_Output
PH0/OSC_IN.Signal=RCC_OSC_IN
PH1/OSC_OUT.Signal=RCC_OSC_OUT
PH2.GPIO_Label=VCC_OUT1
PH2.Signal=GPIO_Output
PH3.GPIO_Label=VCC_OUT2
PH3.Signal=GPIO_Output
PH4.GPIO_Label=VCC_OUT3
PH4.Signal=GPIO_Output
PH5.GPIO_Label=VCC_OUT4
PH5.Signal=GPIO_Output
PH6.Signal=S_TIM12_CH1
PI9.GPIO_Label=NRF24L01_CE
PI9.Signal=GPIO_Output

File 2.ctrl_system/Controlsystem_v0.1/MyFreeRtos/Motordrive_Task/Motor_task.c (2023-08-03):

/**
  ******************************************************************************
  * @file   chassis_task.c
  * @brief  底盘运动控制相关函数
  ******************************************************************************
  * @attention
  *			底盘初始化
  *			判断底盘电机是否正常工作
  *			设置底盘运动模式
  *			底盘模式改变过渡
  *			底盘数据更新，设置底盘控制变量
  *			发送电机控制电流
  ******************************************************************************
  */

#include "Motordrive_Task/Motor_task.h"
#include "Motordrive_Task/Motor_behaviour.h"



#define 	En_MotorTaskRunTime		0	//任务时间统计,用于测试任务情况
#define 	EN_Motor_Info_Print			1	//打印信息控制

//任务时间统计ms
uint32_t	Chassis_StartTime, Chassis_EndTime, Chassis_RunTime;

static void chassis_init(chassis_move_t *chassis_move_init);
static void chassis_feedback_updata(chassis_move_t *chassis_move_updata,uint8_t msg_cnt);
static void chassis_set_mode(chassis_move_t *chassis_move_mode);
static void chassis_loop_ctrl(chassis_move_t *chassis_loop_ctrl);
static void chassis_set_ctrl(chassis_move_t *chassis_set_ctrl);
static void chassisComFeedbackUpdata(chassis_move_t *chassisComFeedbackUpdata);
static void chassisFeedbackDatainit(chassis_move_t *chassisFeedbackInit);
//static void motor_offsetangle_init(chassis_move_t *motor_offsetangle_init);

extern UART_HandleTypeDef huart2;
extern uint8_t rcbuffer[18];

char Chassis_Info_buf[400];			//打印输出信息
char Chassis_Info_buf2[200];

chassis_move_t motor_move;		//定义底盘运动数据
chassis_move_t Com_move;			//定义底盘运动反馈数据

//uint8_t		Remode_Ctrl_Status[3] = {0};	//转向状态控制

uint8_t		START_FLAG = 1;		//默认只获取一次初始值，获取后不再获取
//遥控器操作值获取，用于判断遥控器指令类型
//前后直线控制，Ch1有数据，其余通道为0
//uint16_t	chassis_Ch0;		//Ch0通道	Motor1
//uint16_t	chassis_Ch1;		//Ch1通道	Motor2
//uint16_t	chassis_Ch2;		//Ch2通道	Motor3
//uint16_t	chassis_Ch3;        //Ch2通道	Motor3
//static uint8_t     msg_CNT = 0;            //offset_angle初始化用到

//变量值初始化
//底盘速度环PID值初始化
const static fp32 motor_speed_pid[4] = {M3508_SPEED_PID_KP, M3508_SPEED_PID_KI, M3508_SPEED_PID_KD};
const static fp32 motor_position_pid[4] = {M3508_POSITION_PID_KP, M3508_POSITION_PID_KI, M3508_POSITION_PID_KD};
/**
  * @func 	底盘控制任务
  * @param	argument：空
  * @note	底盘初始化、设置底盘控制模式、底盘数据更新、底盘控制变量设置、底盘控制PID计算、发送电机控制电流
  * @retval None
  */

void Motordrive_task(void *argument)
{
	uint8_t msg_cnt = 0;
	//空闲一段时间，等待其他设备加载成功
	osDelay(MOTORDRIVE_TASK_INIT_TIME);
	vPortEnterCritical();		//进入临界保护
	//底盘初始化
	chassis_init(&motor_move);
	//底盘反馈数据初始化，主要用于反馈底盘运动情况显示

	chassisFeedbackDatainit(&Com_move);

	vPortExitCritical();		//退出临界保护
	//打开电源
	ctrl_power_enable(1);	//直接默认打开

	//主要控制程序
	for(;;)
	{
		if(START_FLAG == 1){
			START_FLAG=0;
			Buzzer_Control(500);		//蜂鸣器提示成功，可以操作遥控器
			osDelay(1000);
		}
#if En_MotorTaskRunTime
		Chassis_StartTime = HAL_GetTick();
#endif
		//设置控制模式
		else {

		chassis_set_mode(&motor_move);
		//测量数据更新
		chassis_feedback_updata(&motor_move, msg_cnt);
        if(msg_cnt < 2)
        	{msg_cnt++;}
        else
        	{msg_cnt = 15;}
		//反馈速度更新
		chassisComFeedbackUpdata(&Com_move);              //反馈数据Cam_move

		//控制变量设置
		chassis_set_ctrl(&motor_move);

		//PID计算
		chassis_loop_ctrl(&motor_move);
		//电机错误处理（未添加）

		//电机发送控制电流
		can1_send_set_moto_current(motor_move.motor_chassis[0].give_current, motor_move.motor_chassis[1].give_current,
				motor_move.motor_chassis[2].give_current, motor_move.motor_chassis[3].give_current);
		//vPortExitCritical();		//退出临界保护

		//电机输出测试
#if EN_Motor_Info_Print
		//遥控器输出测试
//		sprintf(Chassis_Info_buf, " CH0: %d    CH1: %d    CH2: %d	CH3:%d\r\n ",
//				motor_move.chassis_RC->rc.ch0,motor_move.chassis_RC->rc.ch1,motor_move.chassis_RC->rc.ch2,motor_move.chassis_RC->rc.ch3);
//		HAL_UART_Transmit(&huart2, (uint8_t *)Chassis_Info_buf, (COUNTOF(Chassis_Info_buf)-1), 55);
		//电机电流输出测试
//		sprintf(Chassis_Info_buf, " Motor_speed_set[3]:%.f    speed_set[3]: %.f	 speed_feedback[3]:%.2f  give_cur:%d speed_rpm[0]:%d given_cur:%d\r\n ",
//						motor_move.Motor_speed_set[3],
//						motor_move.motor_chassis[3].speed_set,
//						motor_move.motor_chassis[3].speed_feedback,
//						motor_move.motor_chassis[0].give_current,
//						motor_move.motor_chassis[3].chassis_motor_measure->speed_rpm,
//						motor_move.motor_chassis[3].chassis_motor_measure->given_current);

//		sprintf(Chassis_Info_buf, "Motor_set[3]:%d\r\n ",
//				motor_move.Motor_PCctrl->angle[3]);
//		HAL_UART_Transmit(&huart2, (uint8_t *)Chassis_Info_buf, (COUNTOF(Chassis_Info_buf)-1), 55);

//		 printf("M_set[3]:%d cyc_angle[3]=%d  l_angle=%d cyc_llang=%d cyc_cnt=%d sped=%d  cur=%d mot_num=%d\r\n",
//		        		motor_move.Motor_position_set[3],
//						motor_move.motor_chassis[3].chassis_motor_measure->angle,
//						motor_move.motor_chassis[3].chassis_motor_measure->last_angle,
//						motor_move.motor_chassis[3].llast_angle,
//						motor_move.motor_chassis[3].cyc_numberCNT,
//						motor_move.motor_chassis[3].chassis_motor_measure->speed_rpm,
//		                motor_move.motor_chassis[3].give_current,
//						motor_move.motor_chassis[3].mot_cycleNUM);
		 printf("M_set[1]:%d M_set[2]:%d M_set[3]:%d  mot_pos[1]=%d mot_pos[2]=%d mot_pos[3]=%d\r\n",
				        myuart8ctrldata_t.pos[0],
						myuart8ctrldata_t.pos[1],
						myuart8ctrldata_t.pos[2],
						motor_move.Motor_position_set[0],
						motor_move.Motor_position_set[1],
						motor_move.Motor_position_set[2]);
//						motor_move.Motor_position_set[1],
//						motor_move.Motor_position_set[2],
//						motor_move.Motor_position_set[3],
//						motor_move.motor_chassis[0].mot_cycleNUM,
//						motor_move.motor_chassis[1].mot_cycleNUM,
//						motor_move.motor_chassis[2].mot_cycleNUM,
//						motor_move.motor_chassis[3].mot_cycleNUM);

		//遥控器输出测试
#endif

#if En_MotorTaskRunTime
		Chassis_EndTime = HAL_GetTick();
		Chassis_RunTime = Chassis_EndTime - Chassis_StartTime;
		printf("#### Chassis task RunTime = %ld \r\n", Chassis_RunTime);
#endif
		}
		osDelay(5);
	}
}

/*******************************分割线************************************************************/
/**
  * @func 	底盘反馈数据
  * @param
  * @note
  * @retval None
  */
static void chassisFeedbackDatainit(chassis_move_t *chassisFeedbackInit)
{
	//获取底盘电机数据指针，初始化速度PID
	for (uint8_t i = 0; i < 4; i++){
		chassisFeedbackInit->motor_chassis[i].chassis_motor_measure = get_chassis_motor_measure_point(i);
	}
}


/**
  * @func 	底盘数据测量发送反馈更新
  * @param
  * @note	包括测量数据、电机速度、欧拉角度、机器人速度更新
  * @retval None
  */
static void chassisComFeedbackUpdata(chassis_move_t *chassisComFeedbackUpdata)
{
	//底盘电机速度测量值更新
	for (uint8_t i = 0;i < 4; i++){		//更新电机速度
		chassisComFeedbackUpdata->motor_chassis[i].speed_feedback =
				chassisComFeedbackUpdata->motor_chassis[i].chassis_motor_measure->speed_rpm;
        //更新角度值cyclinder_angle
		chassisComFeedbackUpdata->motor_chassis[i].cyclinder_angle = chassisComFeedbackUpdata->motor_chassis[i].chassis_motor_measure->angle
				- chassisComFeedbackUpdata->motor_chassis[i].offset_angle;
	}
}


/****************************************************分割线************************************************************/
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

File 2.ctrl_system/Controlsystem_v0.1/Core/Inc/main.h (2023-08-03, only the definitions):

#define NRF24L01_POWER_Pin GPIO_PIN_13
#define NRF24L01_POWER_GPIO_Port GPIOG
#define NRF24L01_SPI_NSS_Pin GPIO_PIN_4
#define NRF24L01_SPI_NSS_GPIO_Port GPIOE
#define NRF24L01_CE_Pin GPIO_PIN_9
#define NRF24L01_CE_GPIO_Port GPIOI
#define VCC_OUT1_Pin GPIO_PIN_2
#define VCC_OUT1_GPIO_Port GPIOH
#define VCC_OUT2_Pin GPIO_PIN_3
#define VCC_OUT2_GPIO_Port GPIOH
#define VCC_OUT3_Pin GPIO_PIN_4
#define VCC_OUT3_GPIO_Port GPIOH
#define VCC_OUT4_Pin GPIO_PIN_5
#define VCC_OUT4_GPIO_Port GPIOH
#define SPI5_NSS_Pin GPIO_PIN_6
#define SPI5_NSS_GPIO_Port GPIOF
#define IST_LED_Pin GPIO_PIN_3
#define IST_LED_GPIO_Port GPIOG
#define NRF24L01_IRQ_Pin GPIO_PIN_10
#define NRF24L01_IRQ_GPIO_Port GPIOF
#define MPU6500_LED_Pin GPIO_PIN_2
#define MPU6500_LED_GPIO_Port GPIOG
#define PRE_DAT1_Pin GPIO_PIN_3
#define PRE_DAT1_GPIO_Port GPIOC
#define USER_KEY_Pin GPIO_PIN_2
#define USER_KEY_GPIO_Port GPIOB
#define NRF_LED_Pin GPIO_PIN_1
#define NRF_LED_GPIO_Port GPIOG
#define LED1_Pin GPIO_PIN_11
#define LED1_GPIO_Port GPIOE
#define PRE_CLK1_Pin GPIO_PIN_1
#define PRE_CLK1_GPIO_Port GPIOB
#define LED0_Pin GPIO_PIN_14
#define LED0_GPIO_Port GPIOF

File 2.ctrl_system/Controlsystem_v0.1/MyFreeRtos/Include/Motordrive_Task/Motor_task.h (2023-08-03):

#ifndef __CHASSIS_TASK_H__
#define __CHASSIS_TASK_H__

#include <math.h>

#include "Basic_Task/base_calculation.h"
#include "Basic_Task/pid_task.h"
#include <Commnication_Task/CANCom.h>
#include <Commnication_Task/remoteCom.h>
#include <Commnication_Task/Uart8_DMA_RT.h>

#define MOTORDRIVE_TASK_INIT_TIME	500		//这段时间用于初始化底盘任务

//PID参数设置
//底盘电机速度PID参数
//初始值KP=10000.0f、KI=2500.0f、KD = 55.0f、MaxOut=200.0f
#define M3508_SPEED_PID_KP				1.8f
#define M3508_SPEED_PID_KI				0.1f
#define M3508_SPEED_PID_KD				0.0f
#define M3508_SPEED_PID_MAX_OUT			M3508_MAX_CURR
#define M3508_SPEED_PID_MAX_INTE_OUT	2000.0f

#define M3508_POSITION_PID_KP				150.0f
#define M3508_POSITION_PID_KI				0.0001f
#define M3508_POSITION_PID_KD				0.0f
#define M3508_POSITION_PID_MAX_OUT			4000.0f
#define M3508_POSITION_PID_MAX_INTE_OUT	    2000.0f
//M3508电机最大电流值,初始值1000
#define M3508_MAX_CURR	4000.0f
//电机速度最大值限制
#define Motor_MAX_SPEED		1.0f	//单个电机最大速度限制
#define Motor_RCtoM_LEN     0.006f          //遥控器遥感转换为电机转速的比例因子

//电机转速转换为移动速度比例因子
#define M3508_MOTOR_RPM_TO_VECTOR_SEN		0.00042f		//底盘电机速度转换为移动速度
//#define M3508_MOTOR_RPM_TO_VECTOR_SEN		1.0f		//底盘电机速度转换为移动速度


//一阶低通滤波参数
#define MOTOR_FILTER_FRAME_PERIOD			0.002f			//一阶滤波器间隔时间
#define MOTOR_FILTER_TIME_CONST_SET	        0.3333f			//电机时间常数

//定义底盘行为模式
typedef enum {
	//底盘行为模式
	ROBOT_STOP_MODE,				//底盘制动模式
	ROBOT_MOTOR_SPEED_PID_MODE,	    //电机速度环模式
    ROBOT_UART_POSITION_PID_MODE,   //电机位置环模式
}chassis_behaviour_mode_e;

#define ROBOT_STOP_MODE 1
#define ROBOT_MOTOR_SPEED_PID_MODE  2
#define ROBOT_UART_POSITION_PID_MODE  3
//底盘电机控制参数
typedef struct {
	const 	 moto_measure_t	*chassis_motor_measure; 	//获取电机测量参数
	fp32 	 accel;										//获取底盘电机加速度值
	fp32 	 speed_set;									//电机速度遥控器设定值
	fp32 	 speed_feedback;							//电机速度反馈值
	int16_t  give_current;								//有正反转区分，所以是int类型

    int16_t   offset_angle;                            //上电后电机转子初始偏差值 = angle(初始值）
	int16_t   cyclinder_angle;                         //电机转子转角位置(绝对值 增量式) = angle - offset_angle
	int16_t   cyclinder_lastangle;
    int16_t   cyc_angle_err;                            //电机转子两次间差值
    int32_t   cyc_numberCNT;                            //电机转子转数
    int16_t   llast_angle;                              //前第二次转子位置

    int16_t   mot_angle;                                //电机输出轴的角度（°）
    int32_t   mot_angleCNT;                             //电机输出轴总的转子刻度数
    int16_t   mot_cycleNUM;                             //电机输出轴旋转圈数

}chassis_motor_t;

//定义底盘运动参数,多个电机共享参数
typedef struct {
	const RC_Ctl_t 				*chassis_RC;					//遥控器属性
	pid_param_t 				moto_pid_speed[4];				//电机PID计算结构体
	pid_param_t                 moto_pid_position[4];           //电机位置PID结构体
	first_order_filter_t 		chassis_Fir_ord_filt_set_vx;	//底盘一阶滤波器设置x方向
	first_order_filter_t 		chassis_Fir_ord_filt_set_vy;	//底盘一阶滤波器设置y方向
   	first_order_filter_t        motor_Fir_ord_filt_set[6];      //关节电机一阶滤波设置结构体数组
	chassis_behaviour_mode_e	chassis_move_mode;				//定义底盘移动行为模式
	chassis_behaviour_mode_e	last_chassis_mode;				//底盘上次控制状态机，用于底盘过渡作用
	chassis_motor_t				motor_chassis[4];				//底盘四个电机控制属性


	fp32 Motor_speed_set[4];
    int16_t Motor_position_set[4];

    const my_Uart8_RX_Data_t    *Motor_PCctrl;                            //串口控制发送指令
    fp32 Motor_speed_max;
    fp32 Motor_speed_min;


}chassis_move_t;




#endif

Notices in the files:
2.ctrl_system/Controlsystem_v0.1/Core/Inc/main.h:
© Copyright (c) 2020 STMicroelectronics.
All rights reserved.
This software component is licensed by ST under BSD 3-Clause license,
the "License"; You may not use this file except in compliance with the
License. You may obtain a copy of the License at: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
